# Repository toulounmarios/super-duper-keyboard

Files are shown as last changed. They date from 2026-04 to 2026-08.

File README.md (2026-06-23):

helloooooooooooooooooooooo, if you are reading this then you are at the readme section of this repo, so pretty am i right? i know, i know.
im building this project so that i can FINALLY step away from using an old 25 euro gaming keyboard with blue switches ( VERY LOUD ) and make
a compact and aesthetic split keyboad that looks and sounds nice, while also not waking up my entire family at 3am while playing ultrakill or Apex Legends ( both goated btw).
anyways, for anyone who is suprisingly interested in my project here are the key components of the build as well as my key take aways from my first project and some inspo for this.

  first of all, the microcontrollers im using are a pair of seeed xiao nRF52840s, the normal ones will do just fine.
    the pcb was designed on kicad with the libraries from the hackclub stasis event starter project (the split keyboard one) and is manufactured via jlcpcb
   my switches are the kailh choc v2 deep sea silent whale brown switches, due to their tactile yet silent profile.
   for the batteries i havent decided on a li-po battery size for now
  both the case and keycaps ill design after i get the pcb in hand for refernce and ideas 

Now, as for my mistakes, there are afew:

 &emsp; 1) its best to split the work into chunks and finish them consistently. you dont have to do evrything immidiatly, 
    but try to do related tasks back to back to avoid forgetting where you are at in the build process

 &emsp; 2) try to simplify your models in the pcb editor as much as possible. this is because services like jlcpcb change the shipping 
    and manufacturing costs drastically depending on the size of the pcb, but also stuff like the number of layers on your pcb or the pating and stuff

 &emsp; 3) thats it for now

my key inspo for this project was the corne layout for split keyboards and the typeractive corn pcb aluminum case for the pcb and case design
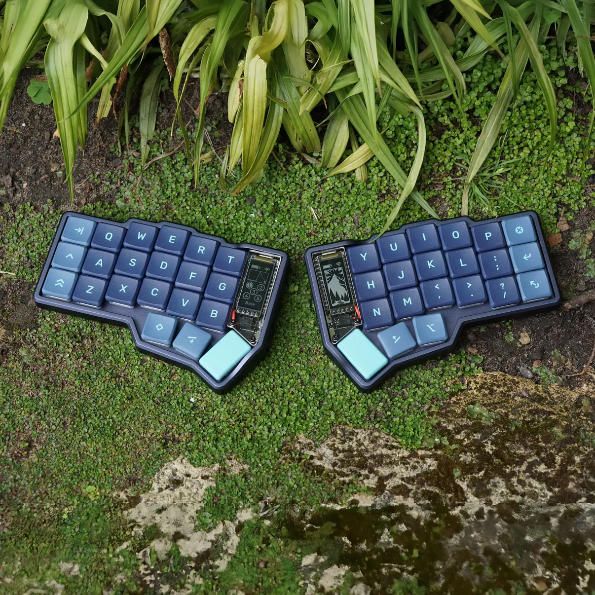
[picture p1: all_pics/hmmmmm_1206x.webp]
inspo_pic


here are the schematics: [schematic](KiCAD_files/keyboard_1.kicad_sch)
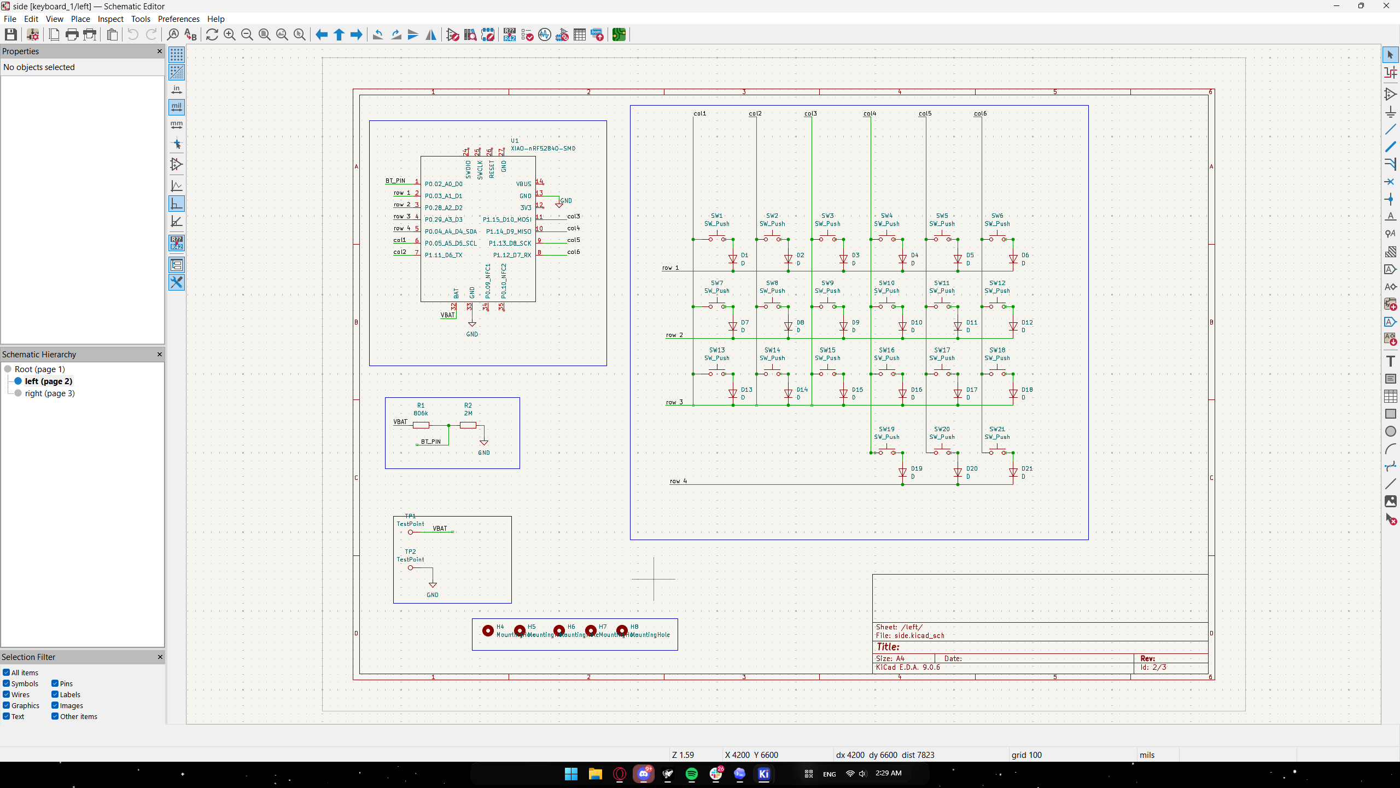
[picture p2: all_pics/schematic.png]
schematic


here is the pcb design for you to put it into jlcpcb: [pcb](KiCAD_files/keyboard_1.kicad_pcb)
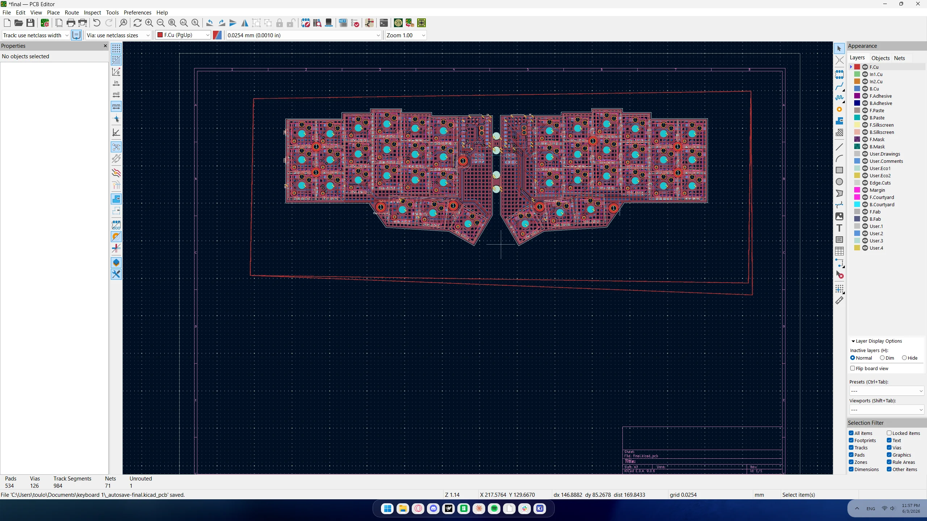
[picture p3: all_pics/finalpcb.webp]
pcb


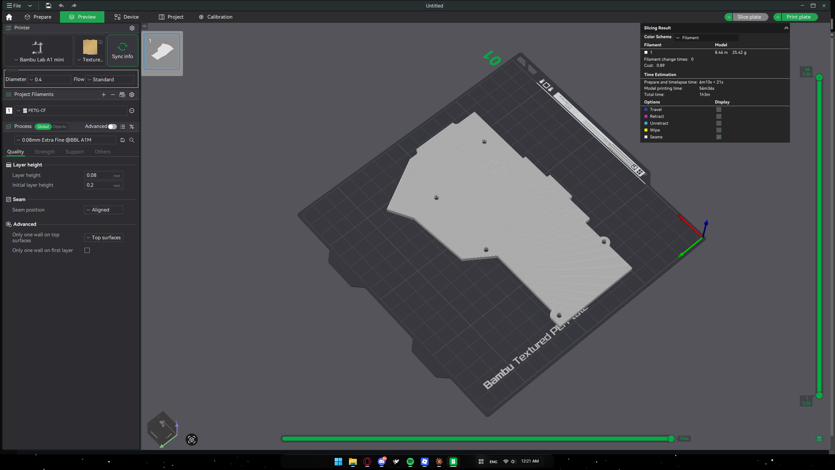
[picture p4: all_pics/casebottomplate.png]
bottom plate
here are pics of the bottom and top plates of the case (all files are in the 3D models folder): 

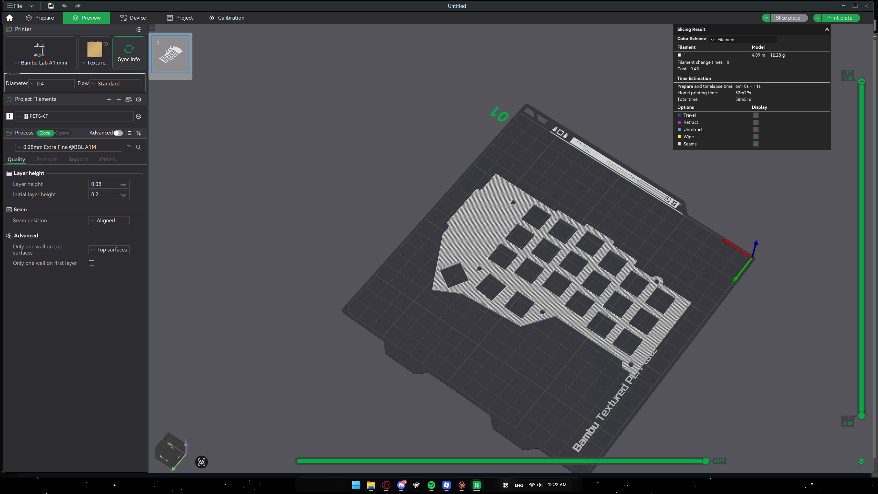
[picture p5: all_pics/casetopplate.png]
top plate


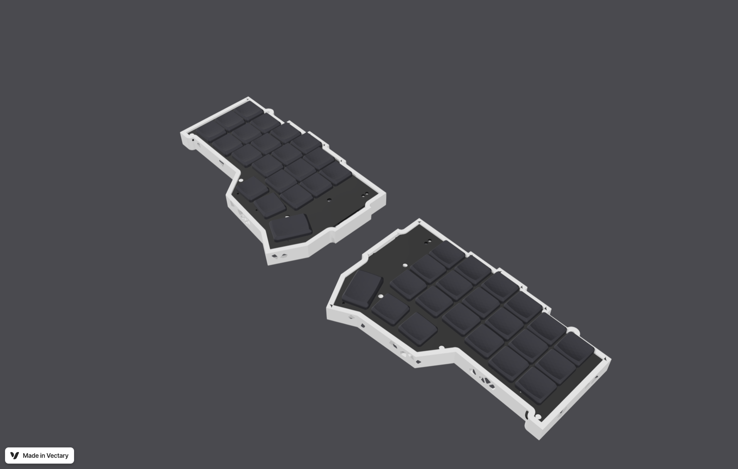
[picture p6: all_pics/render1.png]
render1
also here are some sweet renders! 
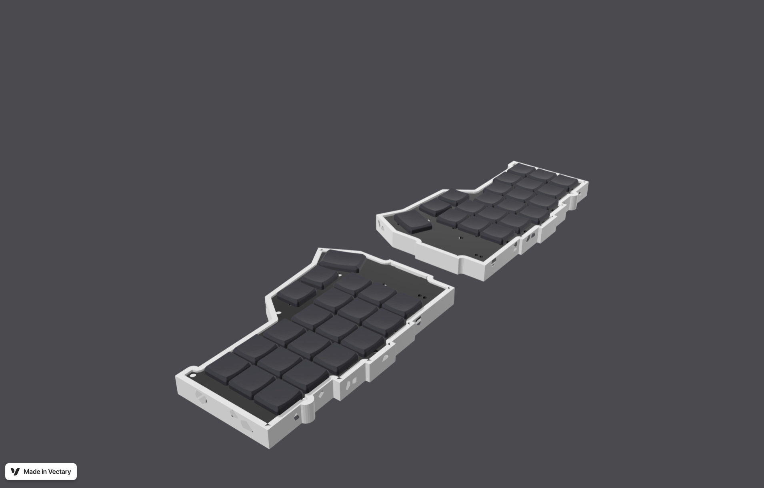
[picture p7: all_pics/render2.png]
render2

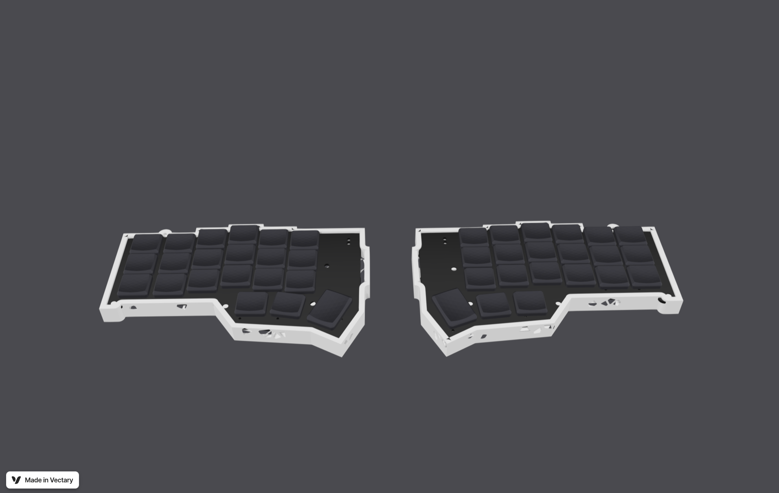
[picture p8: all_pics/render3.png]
render3


here is the BOM :

| Name | Purpose | Qty | Total (USD) | Link | Distributor  | |
|---|---|-----|---|---|---|---|
| | | | | | | |
| | | | | | | |
| Seeed Studio XIAO nRF52840 (XIAO BLE) | they are the microcontrollers | 2 | $19.80 | <a href=https://www.seeedstudio.com/Seeed-XIAO-BLE-nRF52840-p-5201.html>link</a> | seeed studio | |
| | | | | | | |
| | | | | | | |
| 0805 806k resistors | for part of vbat | 100 | $1.68 | <a href=https://www.aliexpress.com/item/1005005184230104.html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>link</a> | aliexpress | |
| | | | | | | |
| | | | | | | |
| 0805 2M resistors | for the bt pin | 100 | $2.18 | <a href=https://www.aliexpress.com/item/1005006984056678.html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>link</a> | aliexpress | |
| | | | | | | |
| | | | | | | |
| 1N4148W T4 SOD-123 diodes | needed for the keyboard matrix | 100 | $1.84 | <a href=https://www.aliexpress.com/item/1005010653199938.html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,scm-url:1007.40050.354490.0,pvid:9ca8f257-295a-4de2-a5ff-3a8f67253366,tpp_buckets:668%232846%238107%231934&pdp_ext_f=%7B%22order%22%3A%221531%22%2C%22eval%22%3A%221%22%2C%22orig_sl_item_id%22%3A%221005010653199938%22%2C%22orig_item_id%22%3A%221005007160563285%22%2C%22sceneId%22%3A%2230050%22%2C%22fromPage%22%3A%22recommend%22%7D&pdp_npi=6%40dis%21EUR%211.34%210.86%21%21%2110.50%216.70%21%40211b612517762807244226998ec4d3%2112000053087454998%21rec%21GR%216010249690%21ABXZ%211%210%21n_tag%3A-29910%3Bd%3A8b9bcfc7%3Bm03_new_user%3A-29895%3BpisId%3A5000000203610259&utparam-url=scene%3ApcDetailTopMoreOtherSeller%7Cquery_from%3A%7Cx_object_id%3A1005010653199938%7C_p_origin_prod%3A1005007160563285>link</a> | aliexpress | |
| | | | | | | |
| | | | | | | |
| kailh choc v2 hotswap sockets | the are the hotswap sockets for my keyswitches | 50  | $5.81 | <a href=https://www.aliexpress.com/item/1005006610506123.html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>link</a> | aliexpress | |
| | | | | | | |
| | | | | | | |
| kailh choc v2 deep sea silent mini whale brown | they are the keyswitches | 50  | $12.97 | <a href=https://www.aliexpress.com/item/1005008382793794.html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>link</a> | aliexpress | |
| | | | | | | |
| | | | | | | |
| the pcb | its the pcb | 5 | $15.80 | (jlcpcb wont let me share my cart so youll have to do it yourself via jlcpcb) | jlcpcb | |
| | | | | | | |
| | | | | | | |
| 3.7v li-po 501350 batteries | they are the batteries for the keyboard | 2 | $11.08 | <a href=https://www.aliexpress.com/item/1005011541459046.html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>link</a> | aliexpress | |
| | | | | | | |
| | | | | | | |
| 8mm m3 screw standoffs | they are the standoffs for the case | 30  | $4.05 | <a href=https://www.aliexpress.com/item/1005002952338852.html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>link</a> | aliexpress | |
| | | | | | | |
| | | | | | | |
| 8mm m3 screws | they are the screws for the build | 50  | $2.89 | <a href=https://www.aliexpress.com/item/1005005618746295.html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>link</a> | aliexpress | |

  important notes for ordering and assembly: 

&emsp;1) the resistors for some reason when pressing the link have a different option selected and you'll have to change it yourself in reference to the BOM
&emsp;2) jlcpcb doesnt let you share a link with your cart, so you'll have to go into the jlcpcb site and import the pcb file and then select the options you want, as well as the color of the pcb.
&emsp;3) in the BOM, im not including filament as part of the cost to make the case and the keycaps, because the price changes drastically depending on what filament you use and so it wouldnt really make sense to add
        it as it would be inaccurate. as a rough estimate tho, with around 250-300 gr of pla filament ( around 6-10$ ), you should be set

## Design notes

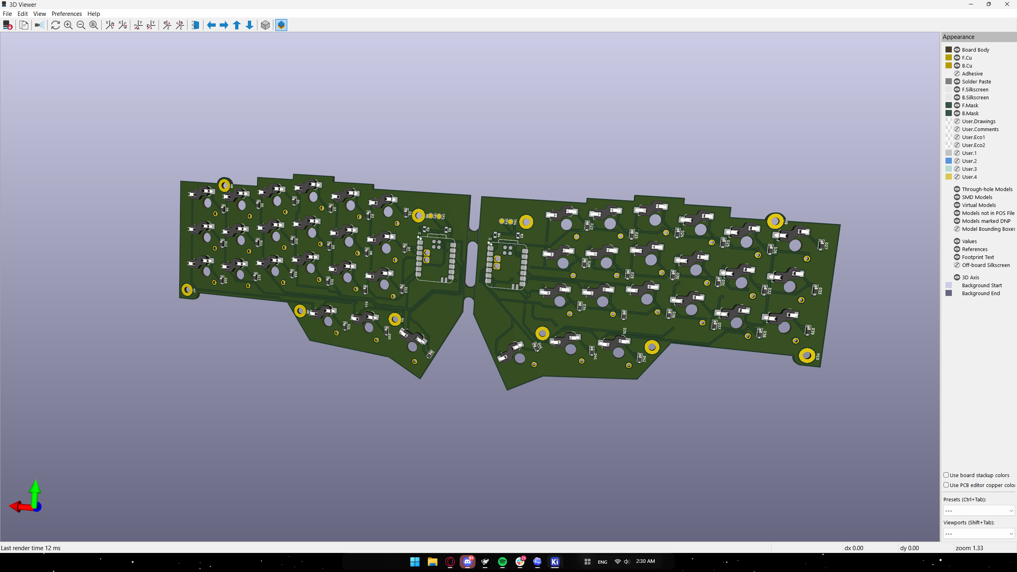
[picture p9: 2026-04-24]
all_pics/3d_model.png

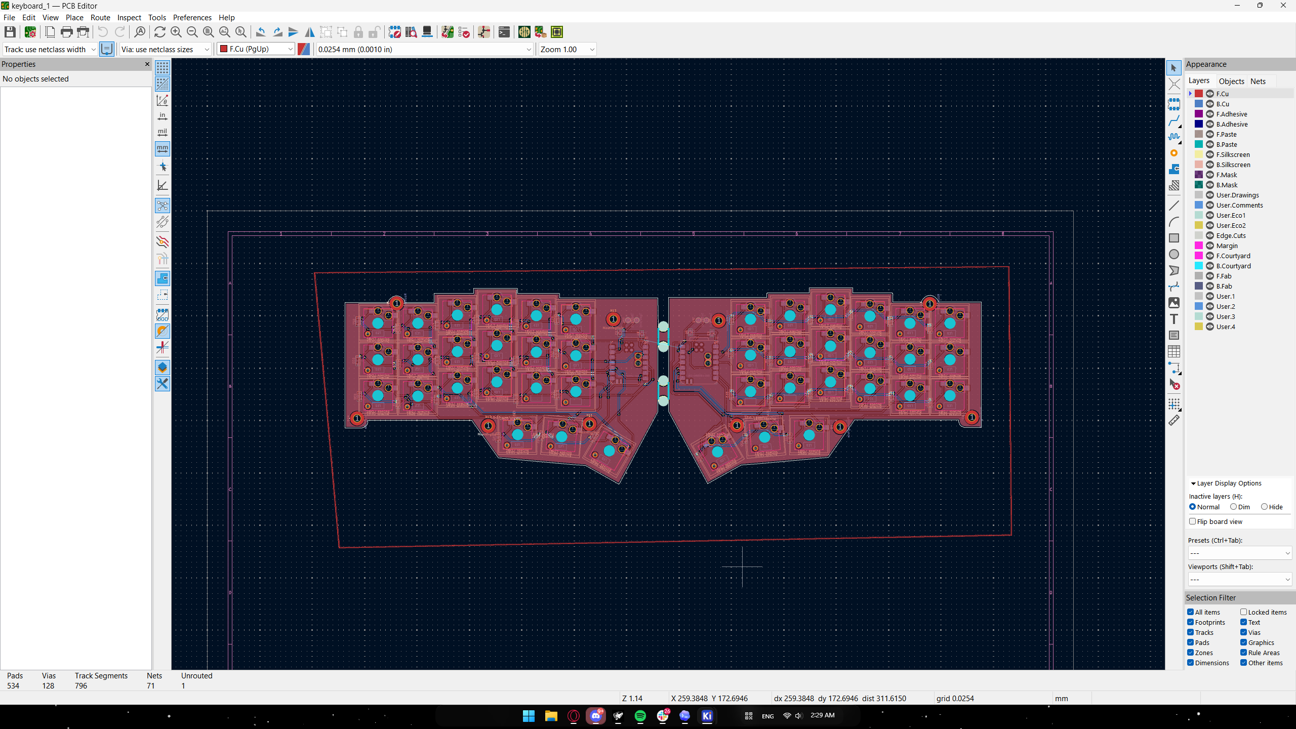
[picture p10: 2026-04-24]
all_pics/pcb_editor.png

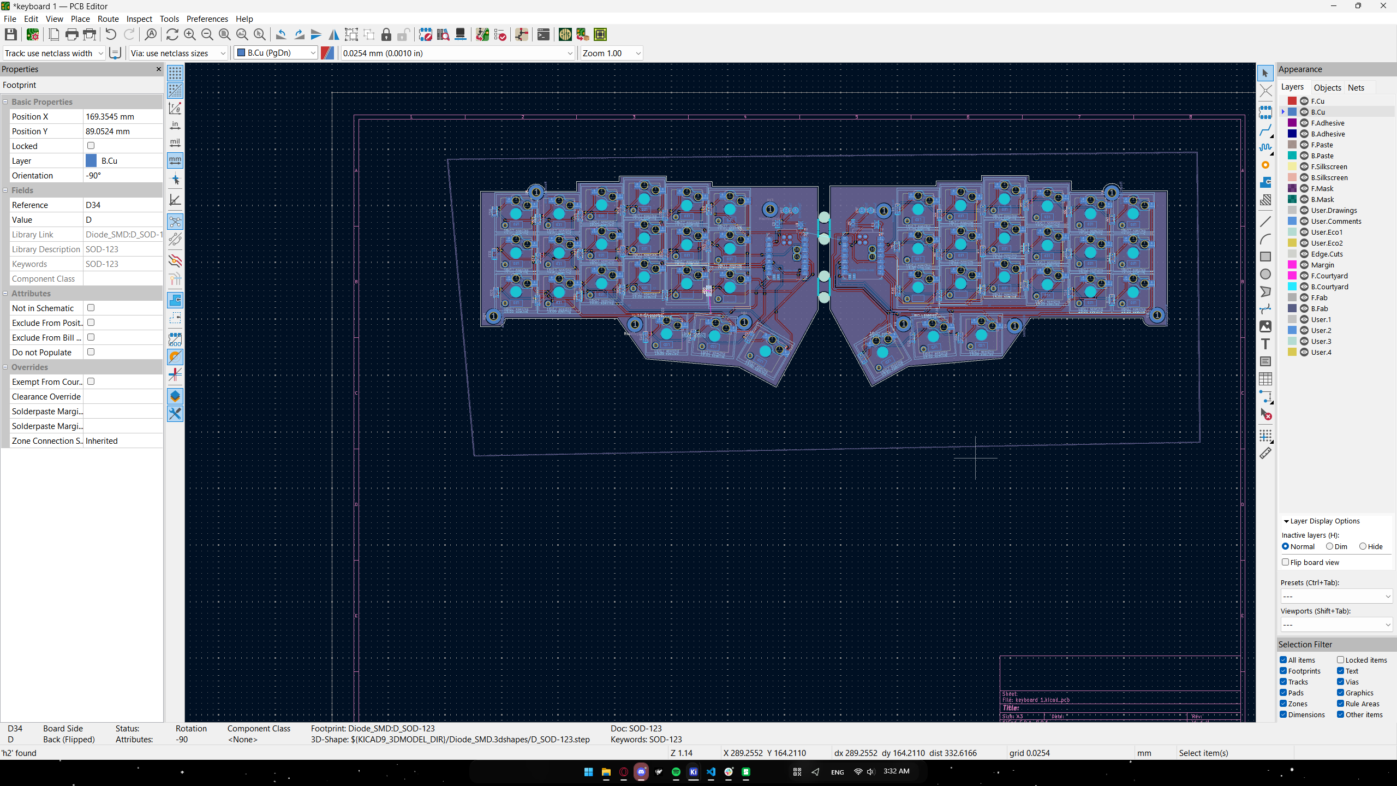
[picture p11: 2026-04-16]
all_pics/pcb.png

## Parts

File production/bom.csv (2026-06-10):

Name | Purpose | Qty | Total (USD) | Link | Distributor
Seeed Studio XIAO nRF52840 (XIAO BLE) | they are the microcontrollers | 2 | $19.80 | https://www.seeedstudio.com/Seeed-XIAO-BLE-nRF52840-p-5201.html | seeed studio
0805 806k resistors | for part of vbat | 100 | $1.68 | https://www.aliexpress.com/item/1005005184230104.html?curPageLogUid=4cgpcI0GnRlD | aliexpress
0805 2M resistors | for the bt pin | 100 | $2.18 | https://www.aliexpress.com/item/1005006984056678.html?curPageLogUid=NDv0RorZTDqo | aliexpress
1N4148W T4 SOD-123 diodes | needed for the keyboard matrix | 100 | $1.84 | https://www.aliexpress.com/item/1005010653199938.html?scm_id=1007.40050.354490.0&scm-url=1007.40050.354490.0 | aliexpress
kailh choc v2 hotswap sockets | the are the hotswap sockets for my keyswitches | 50 | $5.81 | https://www.aliexpress.com/item/1005006610506123.html?cv=c45834a1-6097-4ce5-bd0a-eecf81d5bb63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 | aliexpress
kailh choc v2 deep sea silent mini whale brown | they are the keyswitches | 50 | $12.97 | https://www.aliexpress.com/item/1005008382793794.html?mp=1 | aliexpress
the pcb | its the pcb | 5 | $15.80 | (jlcpcb wont let me share my cart so youll have to do it yourself via jlcpcb) | jlcpcb
3.7v li-po 501350 batteries | they are the batteries for the keyboard | 2 | $11.08 | https://www.aliexpress.com/item/1005011541459046.html?curPageLogUid=aRGigff6t9rL | aliexpress
8mm m3 screw standoffs | they are the standoffs for the case | 30 | $4.05 | https://www.aliexpress.com/item/1005002952338852.html?curPageLogUid=u8OJuwyjTbWf | aliexpress
8mm m3 screws | they are the screws for the build | 50 | $2.89 | https://www.aliexpress.com/item/1005005618746295.html?curPageLogUid=aeUfHf83b7Vf | aliexpress

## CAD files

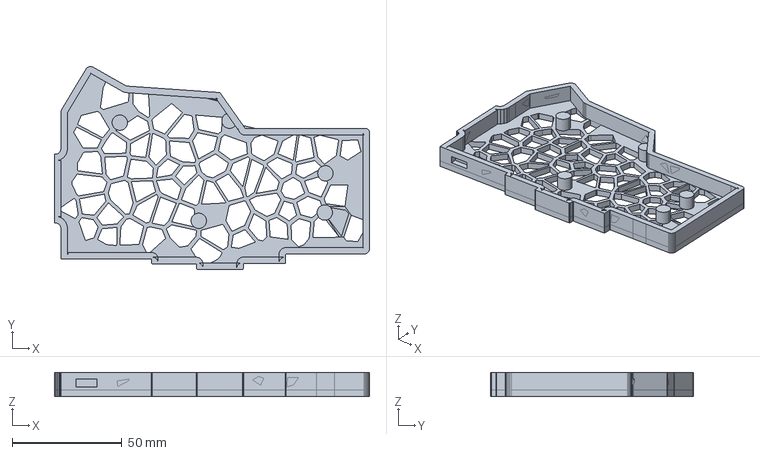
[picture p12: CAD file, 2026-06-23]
Case files/right_tray.stp
143.3 x 92.3 x 11.0 mm

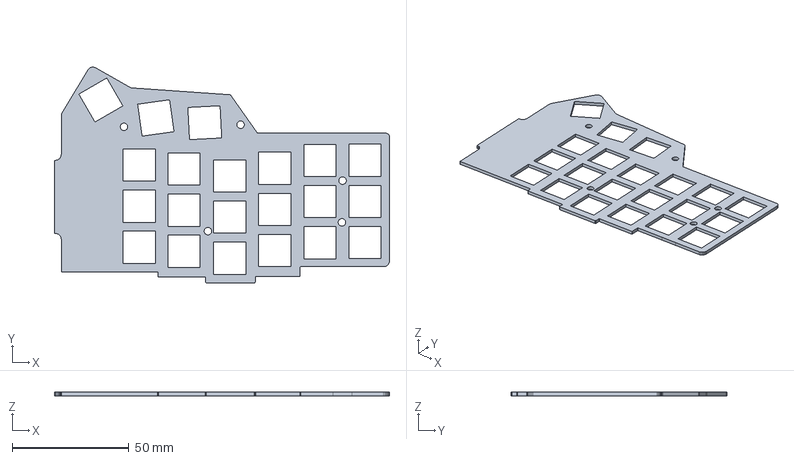
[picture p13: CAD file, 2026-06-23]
Case files/right_switch_plate.stp
143.3 x 92.3 x 1.50 mm

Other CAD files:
Case files/left_tray.stp
Case files/left_switch_plate.stp

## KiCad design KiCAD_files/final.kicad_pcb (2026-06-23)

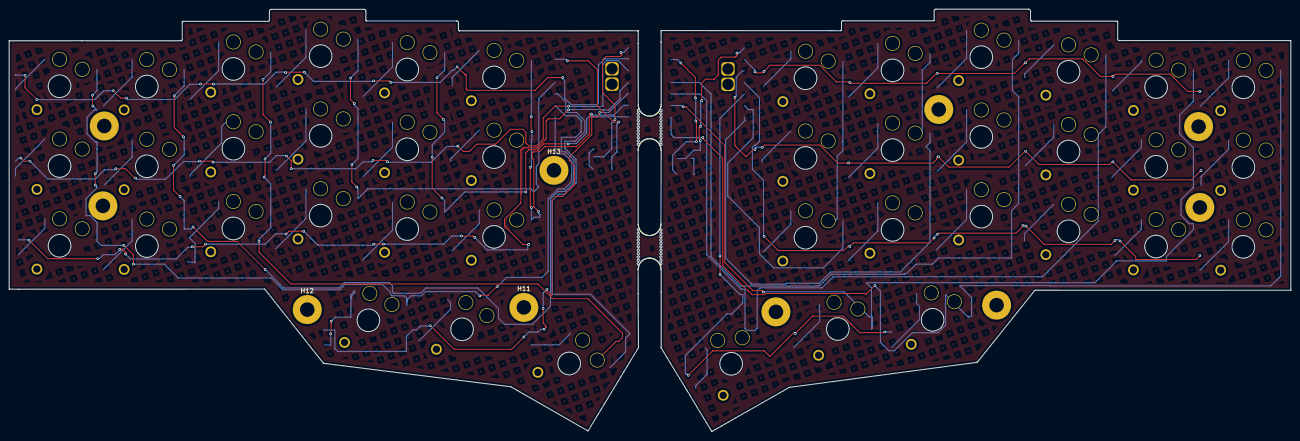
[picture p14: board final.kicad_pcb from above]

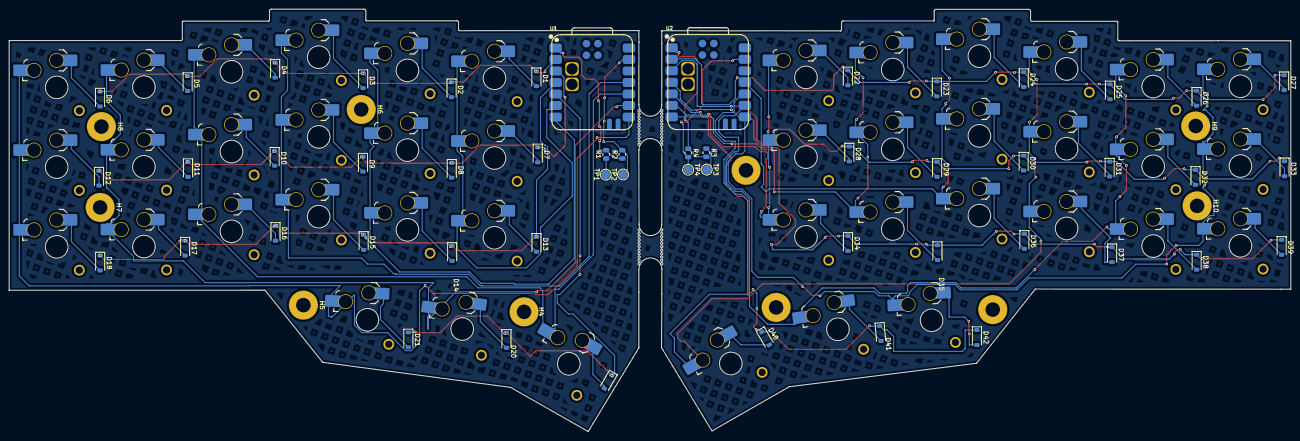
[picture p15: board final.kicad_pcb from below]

Board: 4 copper layers, 282.8 x 93.2 mm, 106 parts (101 on the bottom side), 67 nets.

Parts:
D1, D2, D3, D4, D5, D6, D7, D8, D9, D10, D11, D12, D13, D14, D15, D16, D17, D18, D19, D20, D21, D22, D23, D24, D25, D26, D27, D28, D29, D30, D31, D32, D33, D34, D35, D36, D37, D38, D39, D40, D41, D42: D; D_SOD-123
H2, H3: MountingHole; mouse-bite-5mm-slot
H4, H5, H6, H7, H8, H9, H10, H11, H12, H13: MountingHole; MountingHole_3.2mm_M3_Pad
R1, R3: 806k; R_0805_2012Metric
R2, R4: 2M; R_0805_2012Metric
SW1, SW2, SW3, SW4, SW5, SW6, SW7, SW8, SW9, SW10, SW11, SW12, SW13, SW14, SW15, SW16, SW17, SW18, SW19, SW20, SW21, SW22, SW23, SW24, SW25, SW26, SW27, SW28, SW29, SW30, SW31, SW32, SW33, SW34, SW35, SW36, SW37, SW38, SW39, SW40, SW41, SW42: SW_Push; SW_choc_v2_HS_CPG135001S30_1u
TP1, TP2, TP3, TP4: TestPoint; TestPoint_Pad_D2.0mm
U1, U2: XIAO-nRF52840-SMD; modified-XIAO-nRF52840-SMD

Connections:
/left/BT_PIN: R1.2, R2.1, U1.1 (P0.02_A0_D0)
/left/VBAT: R1.1, TP1.1
/left/col1: SW1.1, SW7.1, SW13.1, U1.6 (P0.05_A5_D5_SCL)
/left/col2: SW2.1, SW8.1, SW14.1, U1.7 (P1.11_D6_TX)
/left/col3: SW3.1, SW9.1, SW15.1, U1.11 (P1.15_D10_MOSI)
/left/col4: SW4.1, SW10.1, SW16.1, SW19.1, U1.10 (P1.14_D9_MISO)
/left/col5: SW5.1, SW11.1, SW17.1, SW20.1, U1.9 (P1.13_D8_SCK)
/left/col6: SW6.1, SW12.1, SW18.1, SW21.1, U1.8 (P1.12_D7_RX)
/left/row 1: D1.1 (K), D2.1 (K), D3.1 (K), D4.1 (K), D5.1 (K), D6.1 (K), U1.2 (P0.03_A1_D1)
/left/row 2: D7.1 (K), D8.1 (K), D9.1 (K), D10.1 (K), D11.1 (K), D12.1 (K), U1.3 (P0.28_A2_D2)
/left/row 3: D13.1 (K), D14.1 (K), D15.1 (K), D16.1 (K), D17.1 (K), D18.1 (K), U1.4 (P0.29_A3_D3)
/left/row 4: D19.1 (K), D20.1 (K), D21.1 (K), U1.5 (P0.04_A4_D4_SDA)
/right/BT_PIN: R3.2, R4.1, U2.1 (P0.02_A0_D0)
/right/VBAT: R3.1, TP3.1
/right/col1: SW22.1, SW28.1, SW34.1, U2.6 (P0.05_A5_D5_SCL)
/right/col2: SW23.1, SW29.1, SW35.1, U2.7 (P1.11_D6_TX)
/right/col3: SW24.1, SW30.1, SW36.1, U2.11 (P1.15_D10_MOSI)
/right/col4: SW25.1, SW31.1, SW37.1, SW40.1, U2.10 (P1.14_D9_MISO)
/right/col5: SW26.1, SW32.1, SW38.1, SW41.1, U2.9 (P1.13_D8_SCK)
/right/col6: SW27.1, SW33.1, SW39.1, SW42.1, U2.8 (P1.12_D7_RX)
/right/row 1: D22.1 (K), D23.1 (K), D24.1 (K), D25.1 (K), D26.1 (K), D27.1 (K), U2.2 (P0.03_A1_D1)
/right/row 2: D28.1 (K), D29.1 (K), D30.1 (K), D31.1 (K), D32.1 (K), D33.1 (K), U2.3 (P0.28_A2_D2)
/right/row 3: D34.1 (K), D35.1 (K), D36.1 (K), D37.1 (K), D38.1 (K), D39.1 (K), U2.4 (P0.29_A3_D3)
/right/row 4: D40.1 (K), D41.1 (K), D42.1 (K), U2.5 (P0.04_A4_D4_SDA)
GND: R2.2, R4.2, TP2.1, TP4.1, U1.13 (GND), U2.13 (GND)
unnamed: D1.2 (A), SW1.2
unnamed: D2.2 (A), SW2.2
unnamed: D3.2 (A), SW3.2
unnamed: D4.2 (A), SW4.2
unnamed: D5.2 (A), SW5.2
unnamed: D6.2 (A), SW6.2
unnamed: D7.2 (A), SW7.2
unnamed: D8.2 (A), SW8.2
unnamed: D9.2 (A), SW9.2
unnamed: D10.2 (A), SW10.2
unnamed: D11.2 (A), SW11.2
unnamed: D12.2 (A), SW12.2
unnamed: D13.2 (A), SW13.2
unnamed: D14.2 (A), SW14.2
unnamed: D15.2 (A), SW15.2
unnamed: D16.2 (A), SW16.2
unnamed: D17.2 (A), SW17.2
unnamed: D18.2 (A), SW18.2
unnamed: D19.2 (A), SW19.2
unnamed: D20.2 (A), SW20.2
unnamed: D21.2 (A), SW21.2
unnamed: D22.2 (A), SW22.2
unnamed: D23.2 (A), SW23.2
unnamed: D24.2 (A), SW24.2
unnamed: D25.2 (A), SW25.2
unnamed: D26.2 (A), SW26.2
unnamed: D27.2 (A), SW27.2
unnamed: D28.2 (A), SW28.2
unnamed: D29.2 (A), SW29.2
unnamed: D30.2 (A), SW30.2
unnamed: D31.2 (A), SW31.2
unnamed: D32.2 (A), SW32.2
unnamed: D33.2 (A), SW33.2
unnamed: D34.2 (A), SW34.2
unnamed: D35.2 (A), SW35.2
unnamed: D36.2 (A), SW36.2
unnamed: D37.2 (A), SW37.2
unnamed: D38.2 (A), SW38.2
unnamed: D39.2 (A), SW39.2
unnamed: D40.2 (A), SW40.2
unnamed: D41.2 (A), SW41.2
unnamed: D42.2 (A), SW42.2

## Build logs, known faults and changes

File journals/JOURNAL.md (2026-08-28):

# all hours journalled here are from my journals from stasis as this project has been transfered from stasis to horizons, thanks

<!--
  This journal is auto generated by Stasis.
-->

# 6/3/2026 9 PM - made the pcb actually nice and not diabolical

_Time spent: 4.666666666666667h_

fixed the ergonomics and the screw hole placements on both sides along with their cases, now its actually pretty . also it now has a diagonal hatch pattern for the copper infill and its gonna look sick. last but not least, i fixed some of the design issues trying to make the case skeletonized and its great now, i think its ready to resubmit 




# 6/3/2026 5 PM - made a render of the keyboard

_Time spent: 2.583333333333333h_

i made a render of the keyboard on vectary and discovered some disign flaws in the pcb design, will fix later










# 5/31/2026 5 PM - fixed the pcb design and adjusted the cad model

_Time spent: 2.833333333333333h_

****as the title says, i fixed the pcb design cause the type c was not accesable and i also made the case skeletonized cause it looks cool. only thing left is to make  a render and resubmit*** * 










# 5/11/2026 1 PM - added firmware and fixed the bom

_Time spent: 6h_

like the title suggests i fixed the bom ( huge pain in the ass ngl) and made firmware for the keyboard. for some reasson the links randomly refused to be shortened after fixing the bom and i cant fix that. also, the firmware compliler on github to me over 30 tries to work and took most if not all the time on this journal, but we made it work :)







# 5/3/2026 9 PM - im pretty sure we did it.

_Time spent: 3.25h_

i  finally have a decent model for the case. after looking online for some inspo, i wanted to try something new and ended up going with a sandwich style case that has the sides exposed in order for me to see the electronics which i think is a cool touch. also, due to the exposed pcb aswell as the standoffs and screws,  anyone making this themselves can customise their keyboard by having color matching screws and pcbs aswell as stuff like the standoffs and the filament color. im probably gonna go with an all black build with bronze or pink details cause i think it will look cool, but a purple pcb with purple screws and a black case would look sick as well ngl. last but not least, i added the files for the case aswell as some photos to the github repo and finalized the bom.  honestly, as this is probably the end of most of this project, with the  assembly and setup being the only things left, i have to thank hackclub and this amazing community for helping and inspiring me to start making projects from scratch and working little by                  little for the end goal and for that i feel nothing but grateful knowing i have people like you on my side
casetopplate

casebottomplate




# 4/24/2026 11 PM - fixed everything that was wrong with the github repo and made it look ALOT better

_Time spent: 3.75h_

fixed my github repo and made it look pretty decent, hopefully i get accepted now, because i really need to get back to working on my final project to get into stasis, aswell as studying for my exams. Also, very important , i dont have a case design yet because i want to see the size of the pcbs in hand and how they are on my desk as well as seeing how it would be comfortable to have them oriented, to design the 3d model optimally, so for now, no 3d model for the 
case :(













# 4/15/2026 10 PM - we are almost done (not really)

_Time spent: 6.116666666666666h_

i got everything in terms of budgeting sorted out and will need to buy the filament and batteries with my own money. jlcpcb took 50 DOLLARS including shipping and tariffs, so we are cooked fr . Also, i got confused with the aliexpress welcome deal and ended up going over the budget by alot. By the way, on the subject of shipping, why does it take over a month for aliexpress to send me a single 400mah battery bro, im not ordering saturn. overall tho, im quit satisfied even tho im freaking out about if im gonna finish in time, the keyswitches i got sound good i think and hopefully are quit enough for me to be able to use my pc at like 2am without waking up my family but who knows, only time will tell lol 














# 4/14/2026 2 PM - i FINALY finished the pcb design

_Time spent: 5.75h_

i finally finished designing the pcb and got the left side done properly, also i finished the edgecuts and added mouse bites. im going to order the pcbs soon. little suggestion for anyone else doing this project, dont even try to copy and flip one of the 2 sides on the pcb editor to make the other, its not possible, will take huge amounts of time and will turn out wrong. either make a oard that is flippable and is the same on both sides so that you dont have a left and right( this is great to save on shipping costs as well as production costs) or make one side and its edge cuts, then copy each row or collumn individual WITHOUT the traces, makeit look symetrical with the ruler tool and then route the traces and add the flipped edge cuts. dont make the same mistakes as me lol




# 3/12/2026 6 AM - pcb designnnnnn

_Time spent: 6h_

my beatiful corne pcb, sadly i lost half of my progress at one point and had to redo it but its fine. turns out when you feel like youre gonna fall asleep on your desk, its a pretty good idea to stop the timelapse and go to sleep, i didnt and as a result my neck hurts and there are like 6 hours of afk footage i had to cut lol, its a good opportunity to observe my beautiful wallpaper tho :3







# 3/8/2026 11 PM - i created the schematics and set up the mod files

_Time spent: 5.75h_

im very proud :3 this took me wayyyyyyyyy more time then it should have but its oki lol. best part is im probably not gonna remember how to do most of the mod file setup in like 3 days so thats fun, anyways imma go eat some fruit and drink a monster. (btw dear reviewer who is checking if my project is going well, what is your favorite drink?) 







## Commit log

2026-04-24 Create kicad files
2026-04-24 Update README with STEP file and BOM details
    Added information about the STEP file and BOM for the project.
2026-04-24 Fix link for Seeed Studio XIAO nRF52840 in README
    Updated the link for Seeed Studio XIAO nRF52840 in the BOM.
2026-04-24 Update README with BOM for custom case components
    Added Bill of Materials (BOM) with components and links.
2026-04-24 Correct BOM formatting in README.md
    Fix formatting issues in BOM section of README.
2026-04-24 Correct BOM formatting in README.md
    Fix formatting issues in the BOM section of README.
2026-04-24 Update resistor entry in README.md
2026-04-24 Clarify PCB link description in README
    Updated the PCB link description for clarity.
2026-04-24 Update PCB description in README.md
    Fixed formatting and improved readability of PCB description.
2026-04-24 Revise README with project overview and BOM
    Updated the README to include project details and components.
2026-04-24 Add ordering and assembly notes to README
    Added important notes regarding ordering and assembly instructions for the PCB.
2026-04-24 Update README with link to PCB step file
2026-04-24 Fix link to PCB step file in README
2026-04-24 Fix link path for PCB step file in README
2026-04-24 Fix link format for PCB step file in README
2026-04-24 Update link to PCB step file location
2026-04-24 Fix link formatting for PCB step file in README
2026-04-24 Rename keyboard 1.step to keyboard_1.step
    [keyboard 1.step, keyboard_1.step]
2026-04-24 Fix schematics link for PCB in README
    Updated the link for the PCB schematics in the README.
2026-04-24 Clarify schematic link and add PCB design reference
    Updated links in README for clarity and added PCB design reference.
2026-04-24 Update README to clarify PCB model reference
2026-04-24 Update PCB design link in README
2026-04-24 Enhance README with image and PCB model link
    Added an image and a link to the PCB 3D model in the README.
2026-04-24 Revise battery details and assembly notes in README
    Updated battery information and added important notes for ordering and assembly.
2026-04-25 Update filament cost explanation in README
    Clarified the explanation regarding filament costs in the BOM.
2026-04-25 Remove LCSC Part # column from 3_bom.csv
    Removed LCSC Part # column from BOM file.
    [3_bom.csv]
2026-04-25 Update 3_bom.csv to include links section
    Added links section to the BOM file.
    [3_bom.csv]
2026-05-03 Add battery and standoff details to README
2026-05-03 Fix formatting for standoffs entry in README
2026-05-03 Include case plate images in README
    Added images of the bottom and top plates of the case.
2026-05-10 Revise BOM table formatting in README
    Updated the BOM table format for better readability.
2026-06-10 Update Untitled spreadsheet - Sheet1 (1).csv
    [Untitled spreadsheet - Sheet1 (1).csv]
2026-06-12 Change PCB image to finalpcb.webp
    Updated PCB image format from PNG to WEBP.
2026-06-17 Create gerber and drill files
